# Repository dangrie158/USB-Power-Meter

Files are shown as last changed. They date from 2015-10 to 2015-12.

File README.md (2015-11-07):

# USB Power Meter

<br /><span xmlns:dct="http://purl.org/dc/terms/" property="dct:title">USB Power Meter</span> by <a xmlns:cc="http://creativecommons.org/ns#" href="http://www.nupo-artworks.de" property="cc:attributionName" rel="cc:attributionURL">Daniel Grießhaber</a> is licensed under a <a rel="license" href="http://creativecommons.org/licenses/by-sa/4.0/">Creative Commons Attribution-ShareAlike 4.0 International License</a>.<br />Based on a work at <a xmlns:dct="http://purl.org/dc/terms/" href="https://github.com/dangrie158/USB-Power-Meter" rel="dct:source">https://github.com/dangrie158/USB-Power-Meter</a>.

Since USB has become more and more a power delivery standard, it would be nice to have a convenient way to measure the power consumption these devices need. Of course there are already power meters out there, but they are just boring or don't have all the features I like.

There are two Versions of the board:
One uses a 7 Segment Display module, the other uses a 0.96” OLED Display. The OLED Version is part of the [Hackaday Square Inch Contest](https://hackaday.io/list/7909-square-inch-project-entrants)

## Links

[The Project on Hackaday](https://hackaday.io/project/8197-usb-power-meter)

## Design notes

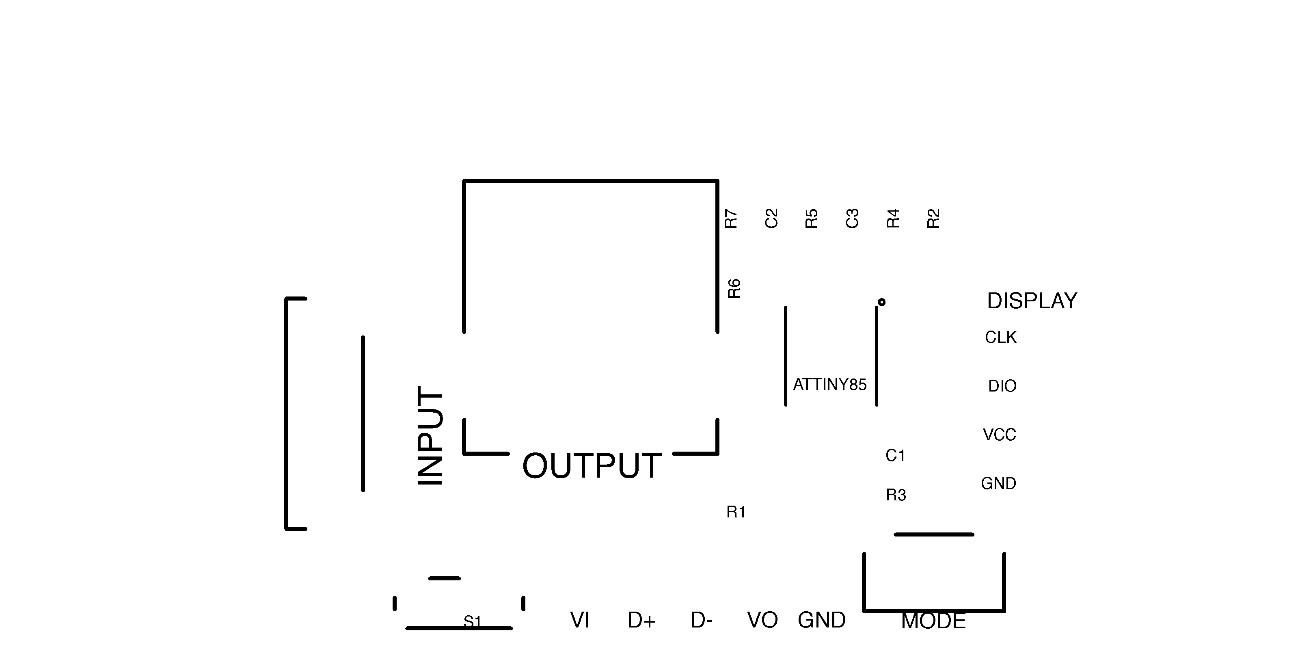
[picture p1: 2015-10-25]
3D Model/eagleUp_Board V1_top_silk.png

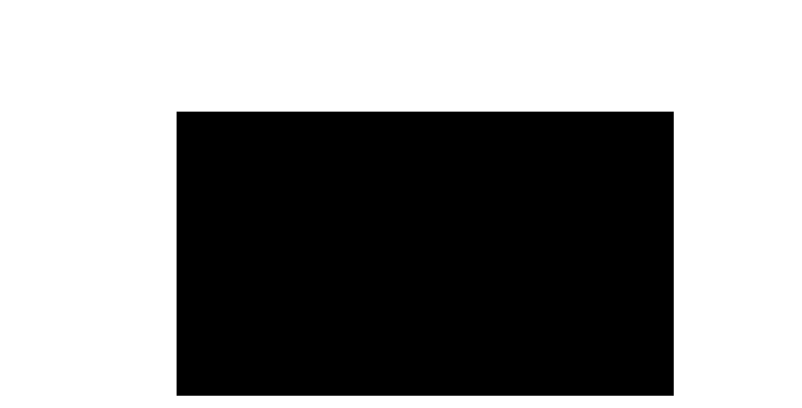
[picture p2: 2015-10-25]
3D Model/eagleUp_Board V1_imagesize.png

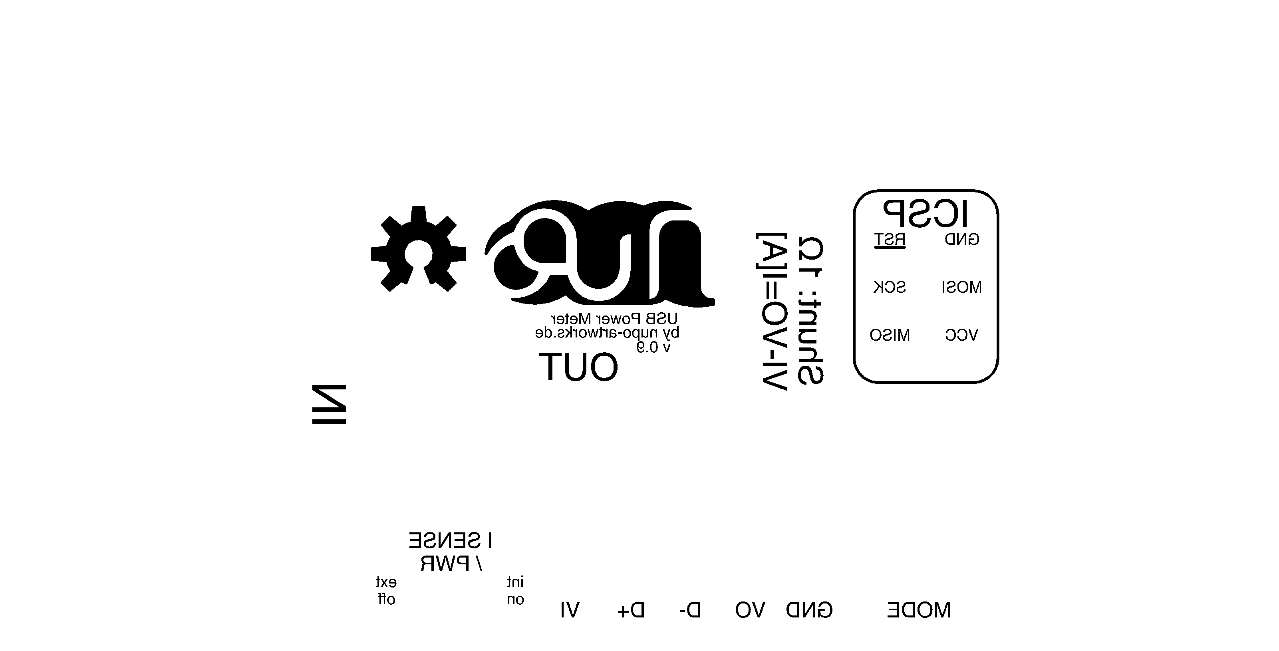
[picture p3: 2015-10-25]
3D Model/eagleUp_Board V1_bottom_silk.png

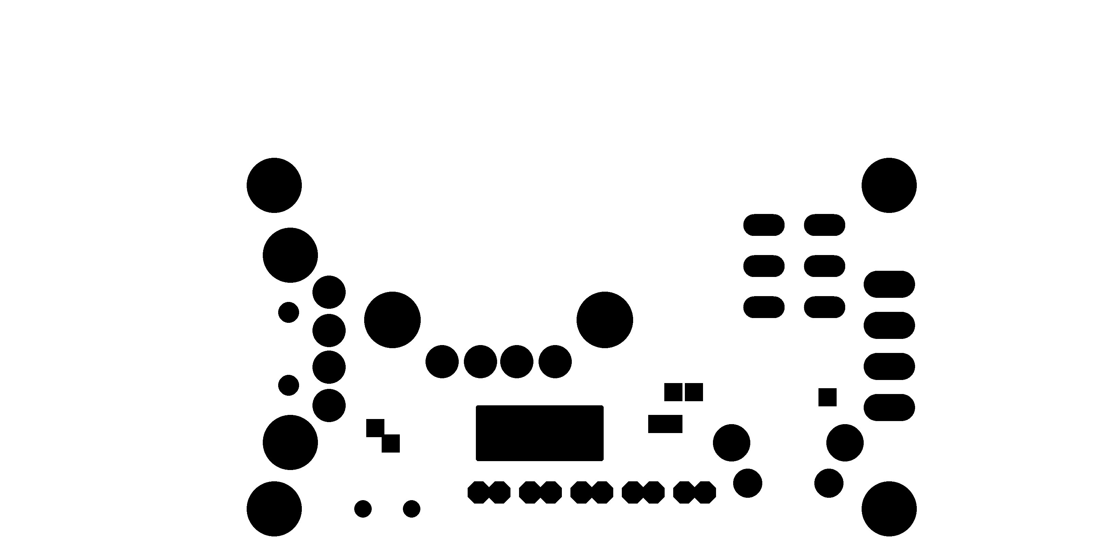
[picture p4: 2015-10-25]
3D Model/eagleUp_Board V1_bottom_mask.png

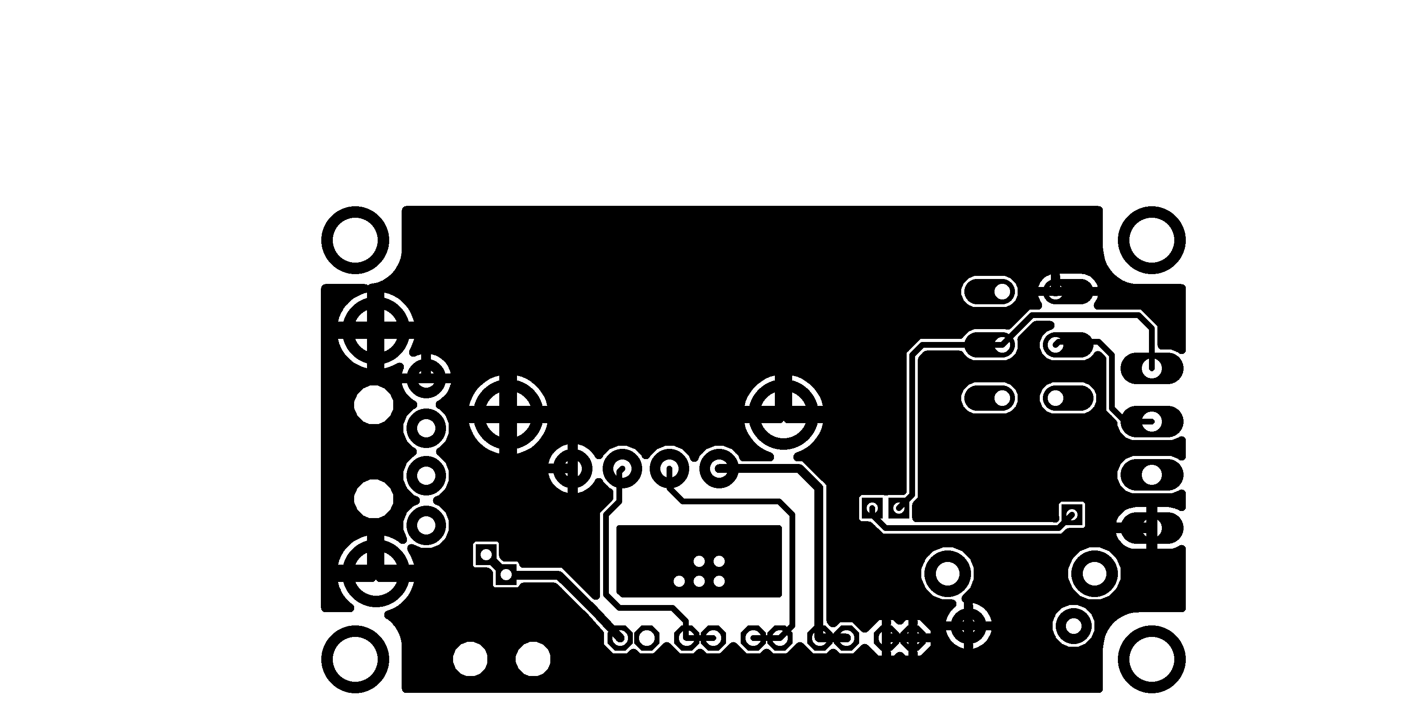
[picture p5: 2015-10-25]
3D Model/eagleUp_Board V1_bottom.png

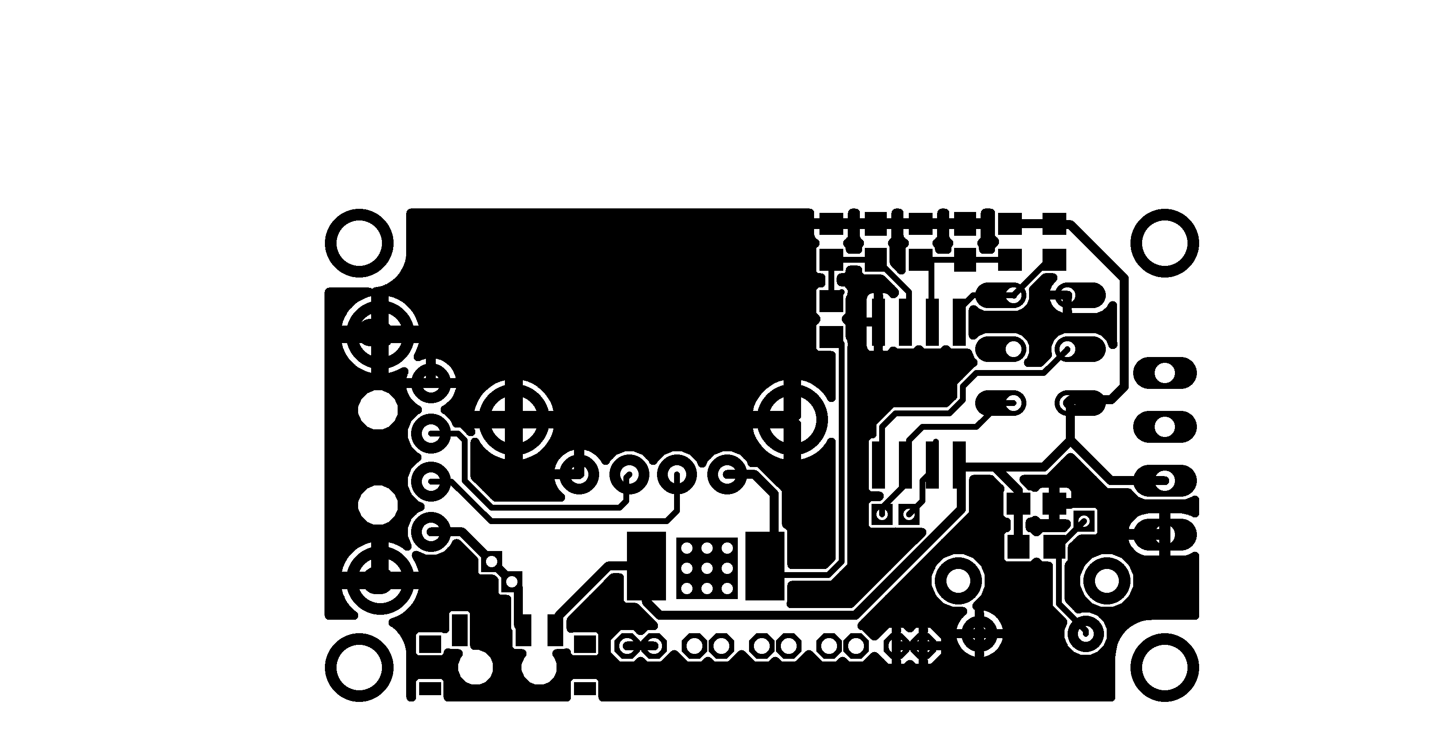
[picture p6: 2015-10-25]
3D Model/eagleUp_Board V1_top.png

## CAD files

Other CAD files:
3D Model/Model.skp

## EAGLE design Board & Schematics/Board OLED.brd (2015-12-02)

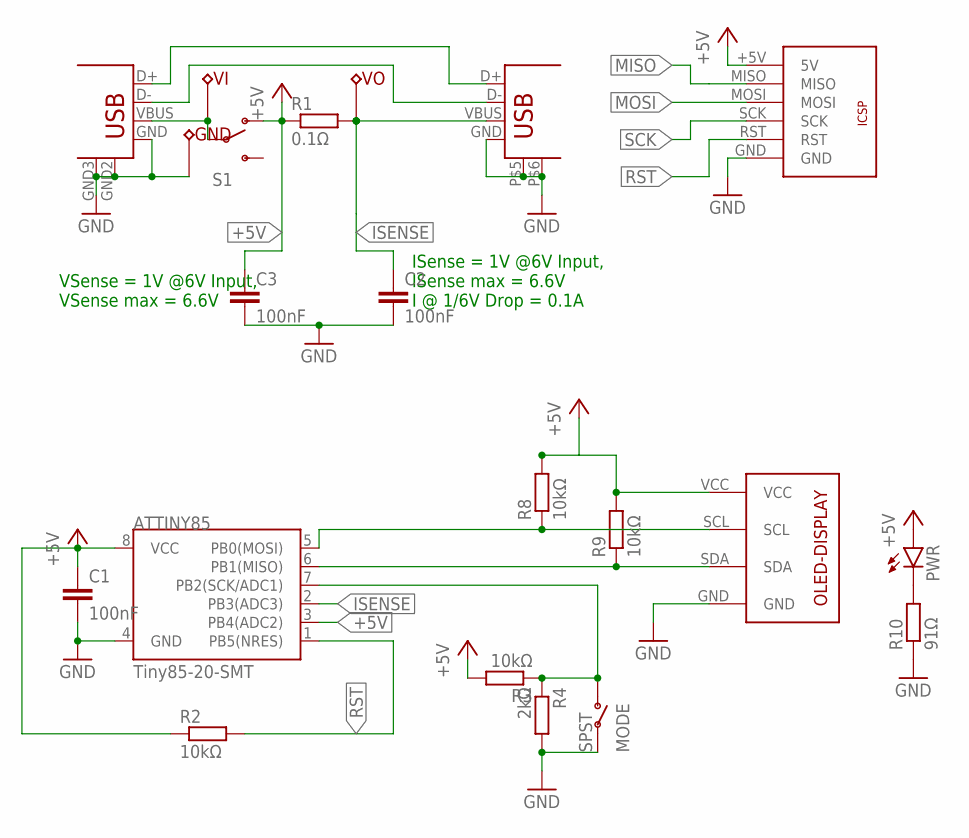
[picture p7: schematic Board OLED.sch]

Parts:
ATTINY85: Tiny85-20-SMT; SO08-EIAJ
C1, C2, C3: 100nF; C0603
GND: TESTPOINT0.5MM-DRILL-WIRE-LOOP; TP-0.5MM-DUAL
INPUT: USB+SHIELDTHROUGHHOLE-MALE; USB-A-H
MODE: SPST; WUERTH-SPST-SMD
OUTPUT: USB+SHIELDTHROUGHOLE-FEMALE; USB-A-S-SILK-THROUGHHOLE
PWR: LED0603; LED-0603
R1: 0.1Ω; R2512
R2, R3, R8, R9: 10kΩ; R0603
R4: 2kΩ; R0603
R10: 91Ω; R0603
S1: SWITCH-SPDT-SMD-A; SWITCH-SPST-SMD-A
U$1: ICSPSMD; ICSP-SMD
U$2: OLED-I2C
VI: TESTPOINT0.5MM-DRILL-WIRE-LOOP; TP-0.5MM-DUAL
VO: TESTPOINT0.5MM-DRILL-WIRE-LOOP; TP-0.5MM-DUAL

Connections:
+5V: ATTINY85.3 (PB4(ADC2)), ATTINY85.8 (VCC), C1.1, C3.1, PWR.A, R1.1, R2.1, R3.2, R8.2, R9.2, S1.1 (O), U$1.+5V (5V), U$2.VCC
GND: ATTINY85.4 (GND), C1.2, C2.2, C3.2, GND.P$1, GND.P$2, INPUT.GND, INPUT.GND2 (S1), INPUT.GND3 (S2), MODE.1, MODE.3, OUTPUT.GND, OUTPUT.P$5 (S1), OUTPUT.P$6 (S2), R4.2, R10.1, U$1.GND, U$2.GND
ISENSE: ATTINY85.2 (PB3(ADC3)), C2.1, OUTPUT.VBUS, R1.2, VO.P$1, VO.P$2
MISO: ATTINY85.6 (PB1(MISO)), R9.1, U$1.MISO, U$2.SDA
MOSI: ATTINY85.5 (PB0(MOSI)), R8.1, U$1.MOSI, U$2.SCL
unnamed: INPUT.D+, OUTPUT.D+
unnamed: INPUT.D-, OUTPUT.D-
unnamed: INPUT.VBUS, S1.2, VI.P$1, VI.P$2
unnamed: PWR.C, R10.2
RST: ATTINY85.1 (PB5(NRES)), R2.2, U$1.RST
SCK: ATTINY85.7 (PB2(SCK/ADC1)), MODE.2 (O), MODE.4 (O), R3.1, R4.1, U$1.SCK

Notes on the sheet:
VSense = 1V @6V Input, VSense max = 6.6V
ISense = 1V @6V Input, ISense max = 6.6V I @ 1/6V Drop = 0.1A

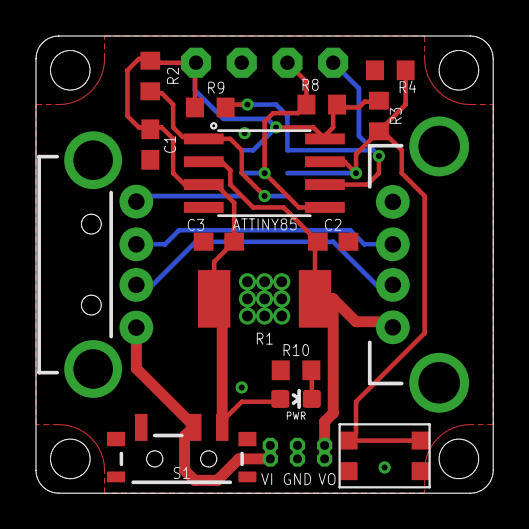
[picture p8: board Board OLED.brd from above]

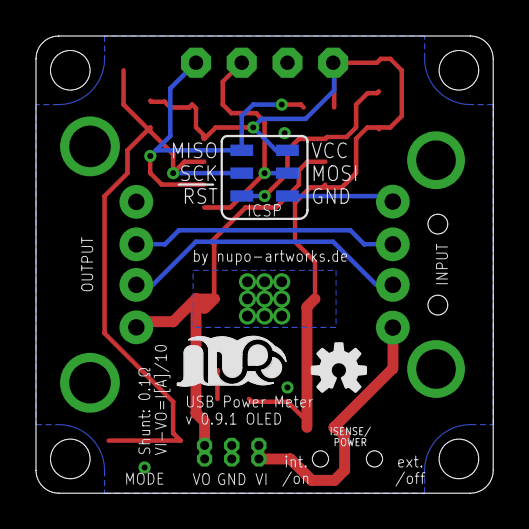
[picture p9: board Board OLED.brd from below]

Board: 2 copper layers, 25.4 x 25.4 mm, 23 parts (3 on the bottom side), 11 nets.

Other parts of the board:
U$3: LOGO-SILKSCREEEN-S
U$4: OSHW-LOGO-S

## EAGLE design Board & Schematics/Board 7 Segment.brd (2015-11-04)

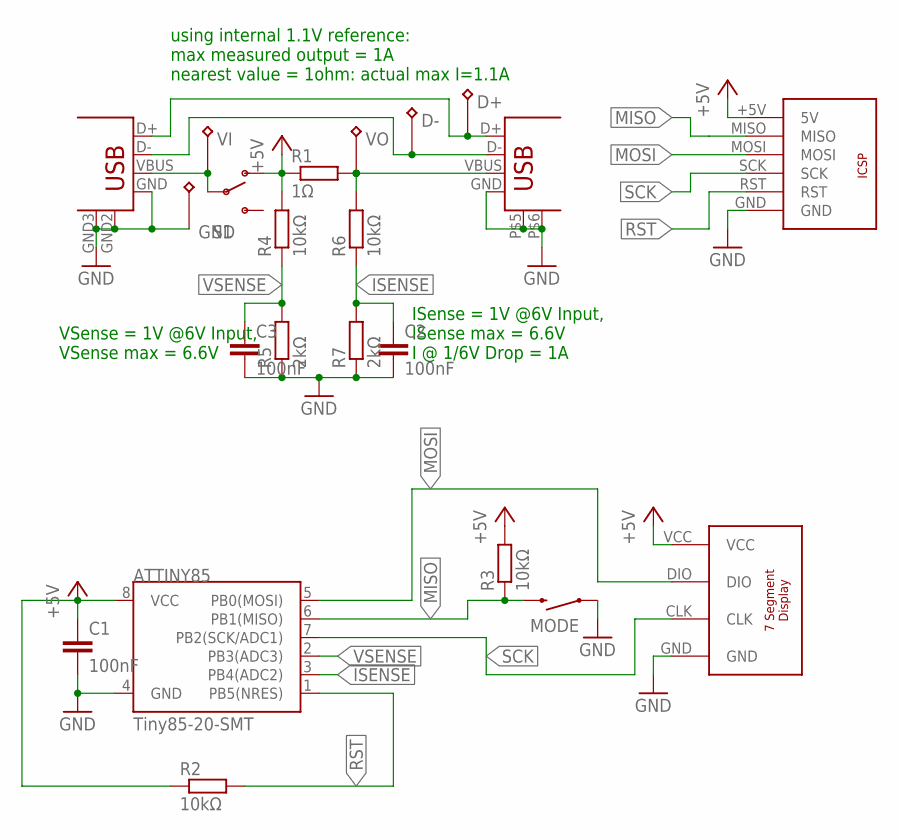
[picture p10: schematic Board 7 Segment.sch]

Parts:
ATTINY85: Tiny85-20-SMT; SO08-EIAJ
C1, C2, C3: 100nF; C0603
D+: TESTPOINT0.8MM-DUAL-DRILL-WIRE-LOOP; TP-0.8MM-DUAL
D-: TESTPOINT0.8MM-DUAL-DRILL-WIRE-LOOP; TP-0.8MM-DUAL
GND: TESTPOINT0.8MM-DUAL-DRILL-WIRE-LOOP; TP-0.8MM-DUAL
INPUT: USB+SHIELDTHROUGHHOLE-MALE; USB-A-H
MODE: SWITCH-MOMENTARY-2SIDE_EZ; TACTILE-PTH-SIDEEZ
OUTPUT: USB+SHIELDTHROUGHOLE-FEMALE; USB-A-S-SILK-THROUGHHOLE
R1: 1Ω; R2512
R2, R3, R4, R6: 10kΩ; R0603
R5, R7: 2kΩ; R0603
S1: SWITCH-SPDT-SMD-A; SWITCH-SPST-SMD-A
U$1: ICSPTHROUGHHOLE; ICSP-THROUGHHOLE
U$2: 7-SEGMENT-I2C
VI: TESTPOINT0.8MM-DUAL-DRILL-WIRE-LOOP; TP-0.8MM-DUAL
VO: TESTPOINT0.8MM-DUAL-DRILL-WIRE-LOOP; TP-0.8MM-DUAL

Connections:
+5V: ATTINY85.8 (VCC), C1.1, R1.1, R2.1, R3.2, R4.2, S1.1 (O), U$1.+5V (5V), U$2.VCC
GND: ATTINY85.4 (GND), C1.2, C2.2, C3.2, GND.P$1, GND.P$2, INPUT.GND, INPUT.GND2 (S1), INPUT.GND3 (S2), MODE.1, OUTPUT.GND, OUTPUT.P$5 (S1), OUTPUT.P$6 (S2), R5.1, R7.1, U$1.GND, U$2.GND
ISENSE: ATTINY85.3 (PB4(ADC2)), C2.1, R6.1, R7.2
MISO: ATTINY85.6 (PB1(MISO)), MODE.2, R3.1, U$1.MISO
MOSI: ATTINY85.5 (PB0(MOSI)), U$1.MOSI, U$2.DIO
unnamed: D+.P$1, D+.P$2, INPUT.D+, OUTPUT.D+
unnamed: D-.P$1, D-.P$2, INPUT.D-, OUTPUT.D-
unnamed: INPUT.VBUS, S1.2, VI.P$1, VI.P$2
unnamed: OUTPUT.VBUS, R1.2, R6.2, VO.P$1, VO.P$2
RST: ATTINY85.1 (PB5(NRES)), R2.2, U$1.RST
SCK: ATTINY85.7 (PB2(SCK/ADC1)), U$1.SCK, U$2.CLK
VSENSE: ATTINY85.2 (PB3(ADC3)), C3.1, R4.1, R5.2

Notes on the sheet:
using internal 1.1V reference: max measured output = 1A nearest value = 1ohm: actual max I=1.1A
VSense = 1V @6V Input, VSense max = 6.6V
ISense = 1V @6V Input, ISense max = 6.6V I @ 1/6V Drop = 1A

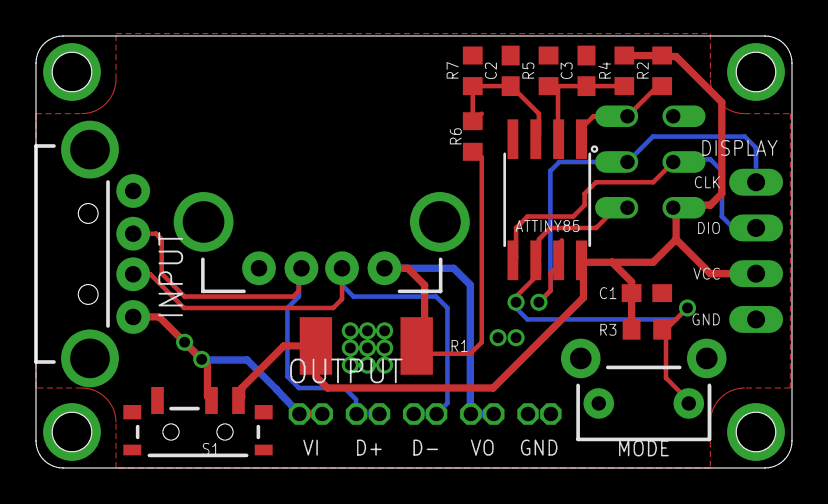
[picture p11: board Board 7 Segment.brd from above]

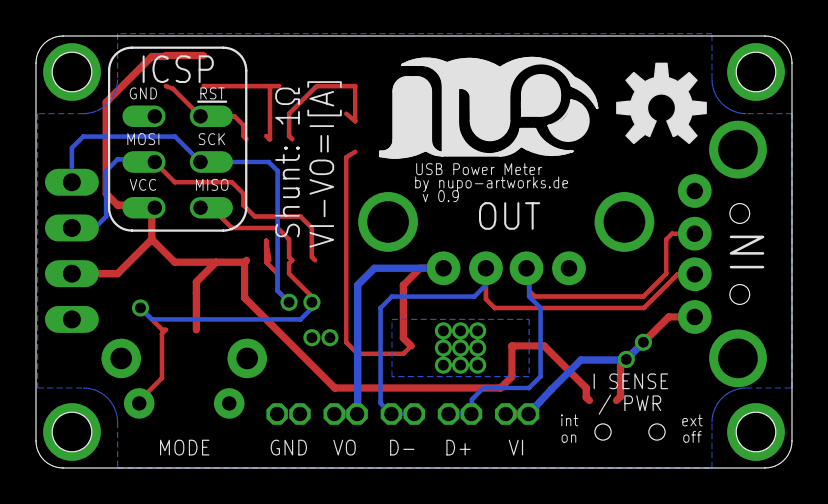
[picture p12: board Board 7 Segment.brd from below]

Board: 2 copper layers, 42.0 x 24.0 mm, 24 parts (3 on the bottom side), 12 nets.

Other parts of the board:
U$3: OSHW-LOGO-M
U$5: LOGO-SILKSCREEN

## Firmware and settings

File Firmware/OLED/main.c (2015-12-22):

#include <util/delay.h>

#include "lib/ADC/ADC.h"
#include "lib/ssd1306xled/ssd1306xled.h"
#include "lib/ssd1306xled/ssd1306xled8x16.h"
#include "logo.h"

// Factor to calculate count number to µA in gain 20 differential mode
#define COUNT_TO_MA_GAINED (11.f * 1000.f) / (20.f * 1024.f)

// Factor to calculate count number to µA in no gain mode
#define COUNT_TO_MA (11.f * 1000.f) / (1024.f)

//Factor to calculate the count number to mV in single ended mode
#define R1 10.0f
#define R2 2.2f
#define VOLTAGE_DIVIDER_RATIO (R2) / ((R1) + (R2))

#define COUNT_TO_MV (1100.0f * (1/(VOLTAGE_DIVIDER_RATIO))) / (1024.f)

#define GAIN_SWITCH_THRESHOLD_UPPER 1000
#define GAIN_SWITCH_THRESHOLD_LOWER 40

//if we measure a voltage below this mV we can assume 
//the switch was pressed and pulled the line low
//if we would have a Vin of 2000mV we couldn't
//work correctly anyway so we can choose this value this high
#define SWITCH_PRESS_MEASURE_THRESHOLD 2000

typedef enum { I_GAIN,
    I_NOGAIN } Mode;
Mode currentMode = I_GAIN;

float measureCurrent()
{
    // configure the ADC to the current Mode
    if (currentMode == I_GAIN) {
        AdcSetDifferentialInputMode(true);
    }
    else if (currentMode == I_NOGAIN) {
        AdcSetDifferentialInputMode(false);
    }

    uint16_t countNumber = AdcGetMultiSample(10);

    float microUnit;
    if (currentMode == I_GAIN) {
        microUnit = countNumber * COUNT_TO_MA_GAINED;
    }
    else if (currentMode == I_NOGAIN) {
        microUnit = countNumber * COUNT_TO_MA;
    }

    // handle the ranging of the gain and no-gain mode
    if (countNumber > GAIN_SWITCH_THRESHOLD_UPPER && currentMode == I_GAIN) {
        currentMode = I_NOGAIN;
    }
    else if (countNumber <= GAIN_SWITCH_THRESHOLD_LOWER && currentMode == I_NOGAIN) {
        currentMode = I_GAIN;
    }

    return microUnit;
}

uint32_t measureVoltage() { 
    //switch to single ended mode on the VIN channel
    AdcSetSingleEndedMode(1); 

    //take the measurement
    uint16_t countNumber = AdcGetMultiSample(10);

    float microUnit = countNumber * COUNT_TO_MV;

    return microUnit;
}

void cleanLine(uint8_t posY, uint8_t numchars){
    //clean the line
    uint8_t posX = 26 + numchars * 8;
    ssd1306_setpos(posX, posY);
    ssd1306_string_font6x8("        ");
    ssd1306_setpos(posX + 12, posY + 1);
    ssd1306_string_font6x8("        ");
}

int main()
{
    static buttonPressed = 0;
    AdcInit();

    _delay_ms(100);
    ssd1306_init();

    ssd1306_fill(0x00); // Clear screen
    ssd1306_draw_bmp(0, 0, 125, 8, logo);
    _delay_ms(1000);
    ssd1306_fill(0x00); // Clear screen

    while (1) {

        //take the measurements
        float currentVoltage = measureVoltage();
        float currentCurrent = measureCurrent();
        float currentPower = (currentVoltage / 1000) * (currentCurrent);

        //use the voltage measurement to determine if the switch was pressed
        if(currentVoltage < SWITCH_PRESS_MEASURE_THRESHOLD && !buttonPressed){
            ssd1306_flip();
            buttonPressed = 1;
            continue;
        }else if (currentVoltage > SWITCH_PRESS_MEASURE_THRESHOLD && buttonPressed){
            //reset the debounce state as soon as we measure 
            //a high enough value again to be sure the button 
            //was released
            buttonPressed = 0;
        }
        
        //convert the measurements to a string
        char voltageString[15];
        itoa((int)currentVoltage, voltageString, 10);

        char currentString[15];
        itoa((int)currentCurrent, currentString, 10);

        char powerString[15];
        itoa((int)currentPower, powerString, 10);

        //draw the voltage
        ssd1306_setpos(0, 1);
        ssd1306_string_font6x8("U =");
        ssd1306_char_f8x16(25, 0, voltageString);
        ssd1306_string_font6x8("mV");
        cleanLine(0, strlen(voltageString));

        ssd1306_setpos(0, 4);
        ssd1306_string_font6x8("I =");
        ssd1306_char_f8x16(25, 3, currentString);
        ssd1306_string_font6x8("mA");
        cleanLine(3, strlen(currentString));

        //draw the multiplier indicator at the top right
        if (currentMode == I_GAIN) {
            ssd1306_setpos(64, 4);
            ssd1306_string_font6x8(" (x20)");
        }
        

        ssd1306_setpos(0, 7);
        ssd1306_string_font6x8("P =");
        ssd1306_char_f8x16(25, 6, powerString);
        ssd1306_string_font6x8("mW");

        cleanLine(6, strlen(powerString));

        //_delay_ms(500);
    }
}

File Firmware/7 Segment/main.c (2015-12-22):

#include <util/delay.h>

#include "lib/TM1637/TM1637Display.h"
#include "lib/ADC/ADC.h"

//Factor to calculate count number to µA in gain 20 differential mode
#define COUNT_TO_UA_GAINED (11.f * 1000.f)/(20.f * 1024.f)

//Factor to calculate count number to µA in no gain mode
#define COUNT_TO_UA (11.f * 1000.f)/(1024.f)

#define GAIN_SWITCH_THRESHOLD_UPPER 1000
#define GAIN_SWITCH_THRESHOLD_LOWER 1

typedef enum {I_GAIN, I_NOGAIN, U_IN, U_OUT} Mode;
Mode currentMode = I_GAIN;

int main(){
	TM1637DisplayInit();
	  
	AdcInit();

	AdcSetDifferentialInputMode(true);
	//AdcSetSingleEndedMode(3);

	TM1637DisplaySetBrightness(0x0f);

    while(1){


    	//configure the ADC to the current Mode
    	if(currentMode == I_GAIN){
    		AdcSetDifferentialInputMode(true);
    	}else if(currentMode == I_NOGAIN){
    		AdcSetDifferentialInputMode(false);
    	}


    	uint16_t countNumber = AdcGetMultiSample(100);

    	//handle the ranging of the gain and no-gain mode
    	if(countNumber > GAIN_SWITCH_THRESHOLD_UPPER && currentMode == I_GAIN){
    		currentMode = I_NOGAIN;
    		continue;
    	}else if(countNumber <= GAIN_SWITCH_THRESHOLD_LOWER && currentMode == I_NOGAIN){
    		currentMode = I_GAIN;
    		continue;
    	}

    	float microUnit;
    	if(currentMode == I_GAIN){
    		microUnit = countNumber * COUNT_TO_UA_GAINED;
    	}else if(currentMode == I_NOGAIN){
    		microUnit = countNumber * COUNT_TO_UA;
    	}

	  	TM1637DisplayShowNumberDec(microUnit, true);
	  	_delay_ms(500);
    }
}

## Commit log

2015-10-25 added schematic and board layout
    [Board 7 Segment.brd, Board 7 Segment.sch]
2015-10-25 added 3D Model of the assembled board with 7 segment display
    [Model.skp]
2015-10-25 added a Case for 3D Printing
2015-10-25 added new Version of the board that fits on a square inch and uses an OLED display
    [Board OLED.brd, Board OLED.sch]
2015-10-25 switched to markdown README
2015-11-04 removed cream from bottom ICSP Header
    [Board OLED.brd, Board OLED.sch]
2015-11-04 added soldermask from vias
    [Board OLED.brd]
2015-11-04 added soldermask on vias for 7 segment version
    [Board 7 Segment.brd]
2015-11-11 fixed silkscreen and schematic designator for new, smaller shunt
    [Board OLED.brd, Board OLED.sch]
2015-11-21 remove attenuation from OLED variant
    [Board OLED.brd, Board OLED.sch]
2015-11-23 switched differential measure polarity
    [Board OLED.brd, Board OLED.sch]
2015-11-24 added attenuation resistor network to mode switch pin
    [Board OLED.brd, Board OLED.sch]
2015-12-02 added Gerbers for both versions
    [Board 7 Segment.drills.xln, Board OLED.drills.xln]
2015-12-02 fixed component layout
    [Board OLED.brd]

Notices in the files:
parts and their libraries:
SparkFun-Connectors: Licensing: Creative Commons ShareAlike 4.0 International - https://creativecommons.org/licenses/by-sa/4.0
